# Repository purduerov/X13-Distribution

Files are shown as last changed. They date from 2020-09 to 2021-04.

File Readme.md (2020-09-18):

# Readme for X13-Distribution

Whenever you make a new part, download the datasheet and save it here _**and**_ with the part in the parts library

Always pull other people's changes before beginning to work
`git pull`

Be sure to push your changes after  working on them. Run:
1. `git add .` to add any files in this directory or a subdirectory
or `git add -u` to add any modified files
2. (Optional) `git clean -nX` to see what ignored files can be removed
	`git clean -fX` removes ignored files (Eagle backups)
3. `git commit -m "helpful commit message"` with a description of the work that you did
4. `git push` to push your work to github

Other helpful commands
* `git status` says information about modified and staged files
* `git log` shows the recent commits of the repository
* `git log filename.extension` show the recent commits for just that file
* `git checkout first-couple-letter-of-commit-id` lets you go back to a previous version
* `git checkout master` brings you back to the latest commit
* `git tag` lists the tags
* `git tag -a orderX -m "the version of the board placed for the X'th order"` tag a specific commit
* `git push --tags` needed to push tags to remote
* `git show orderX` show the commit log for the given tag
* `git checkout orderX` go back and interact with the files at the tagged commit

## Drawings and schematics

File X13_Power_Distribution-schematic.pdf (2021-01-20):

## 2 48V_POE

## 6 TETHER

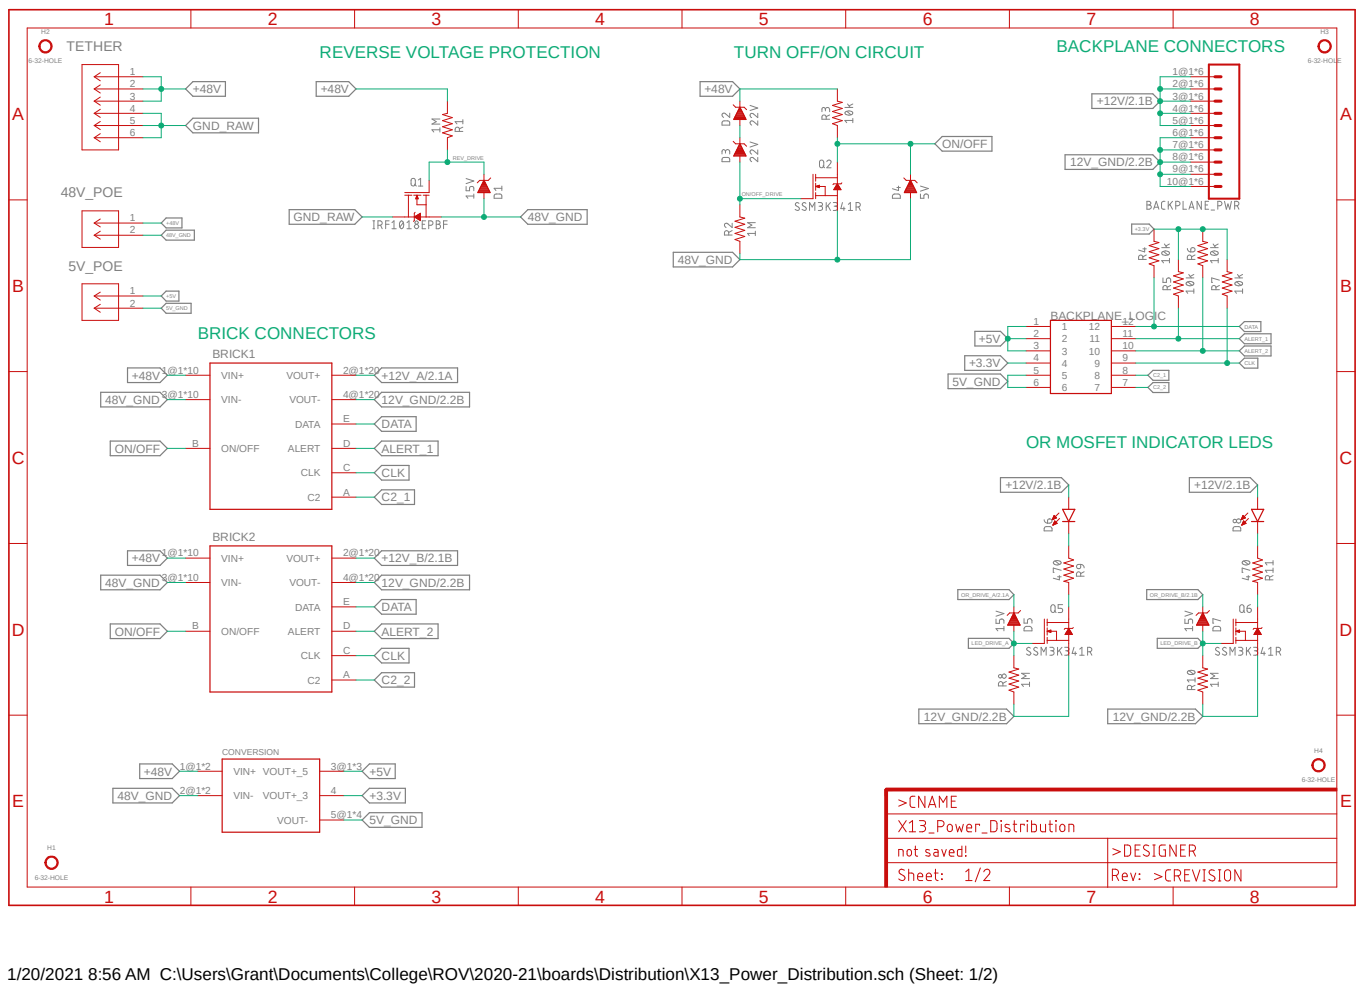
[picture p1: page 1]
2 5V_POE; 6-32-HOLE; VIN+ 1@1*2; VIN- 2@1*2; VOUT+_5; VOUT+_3; VOUT-; CONVERSION; 12 BACKPLANE_LOGIC; VIN+ 1@1*10; VIN- 3@1*10; VOUT+; ON/OFF B; DATA; ALERT; CLK; A BRICK1; A BRICK2; ON/OFF_DRIVE; ON/OFF; 48V_GND; CLK CLK; DATA DATA; 12V_GND/2.2B; GND_RAW; REV_DRIVE; OR_DRIVE_A/2.1A; OR_DRIVE_B/2.1B; ALERT_2; ALERT_1 ALERT_1; 5V_GND; LED_DRIVE_A; LED_DRIVE_B; REVERSE VOLTAGE PROTECTION; TURN OFF/ON CIRCUIT; BACKPLANE CONNECTORS; BRICK CONNECTORS

OR MOSFET INDICATOR LEDS

1/20/2021 8:56 AM C:\Users\Grant\Documents\College\ROV\2020-21\boards\Distribution\X13_Power_Distribution.sch (Sheet: 1/2)

LM5050

A

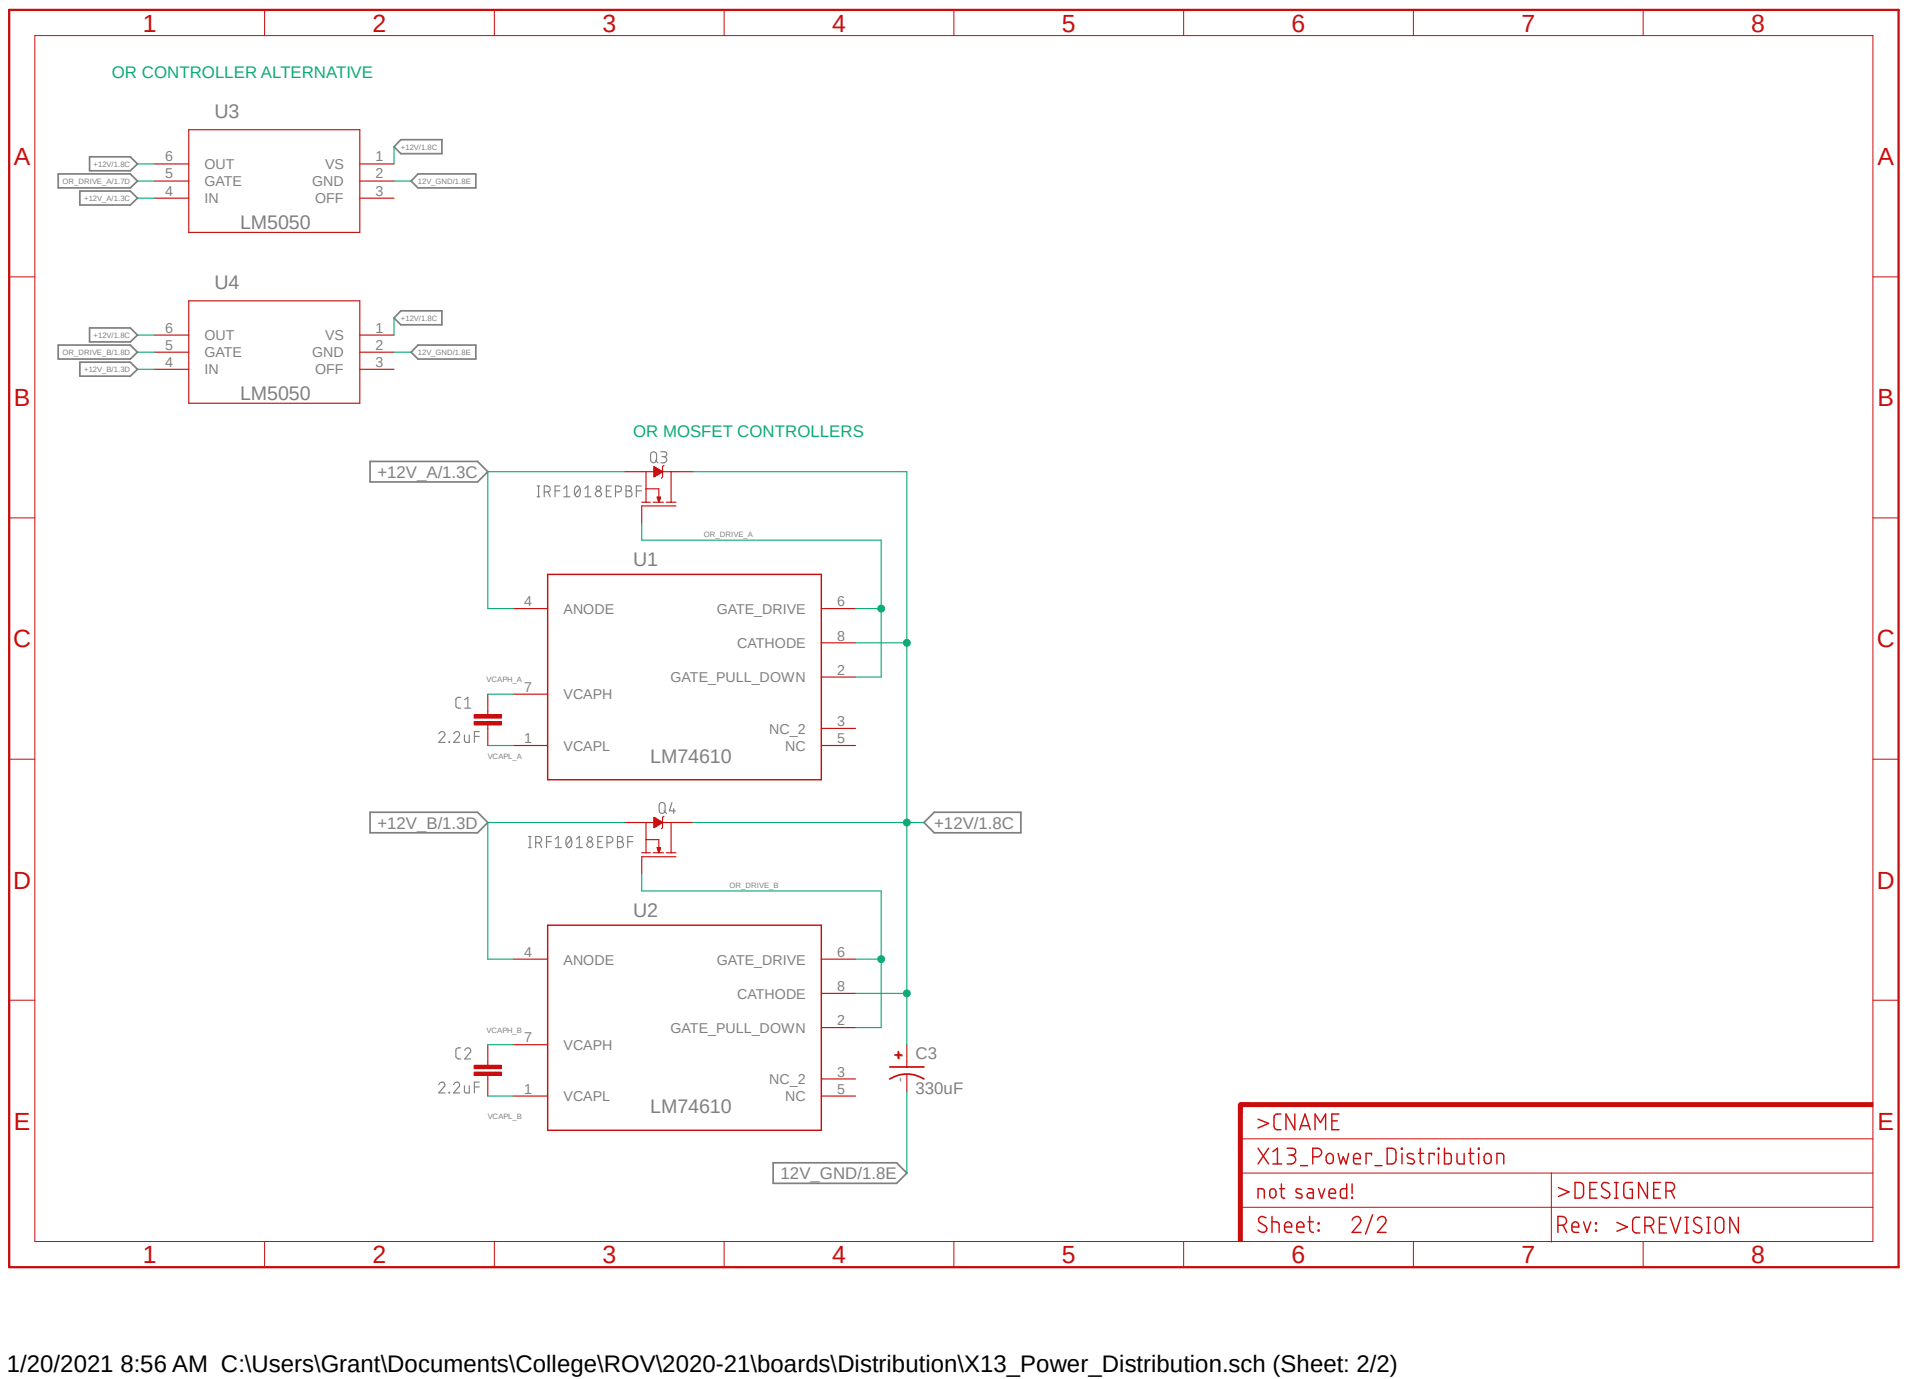
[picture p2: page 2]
VCAPL 1; GATE_PULL_DOWN; ANODE 4; GATE_DRIVE; VCAPH 7; CATHODE; GND; OFF; GATE 5; OUT 6; 12V_GND/1.8E; VCAPH_B; VCAPL_B; VCAPL_A; VCAPH_A; OR_DRIVE_A; OR_DRIVE_A/1.7D; OR_DRIVE_B; OR_DRIVE_B/1.8D A

OR CONTROLLER ALTERNATIVE

OR MOSFET CONTROLLERS

1/20/2021 8:56 AM C:\Users\Grant\Documents\College\ROV\2020-21\boards\Distribution\X13_Power_Distribution.sch (Sheet: 2/2)

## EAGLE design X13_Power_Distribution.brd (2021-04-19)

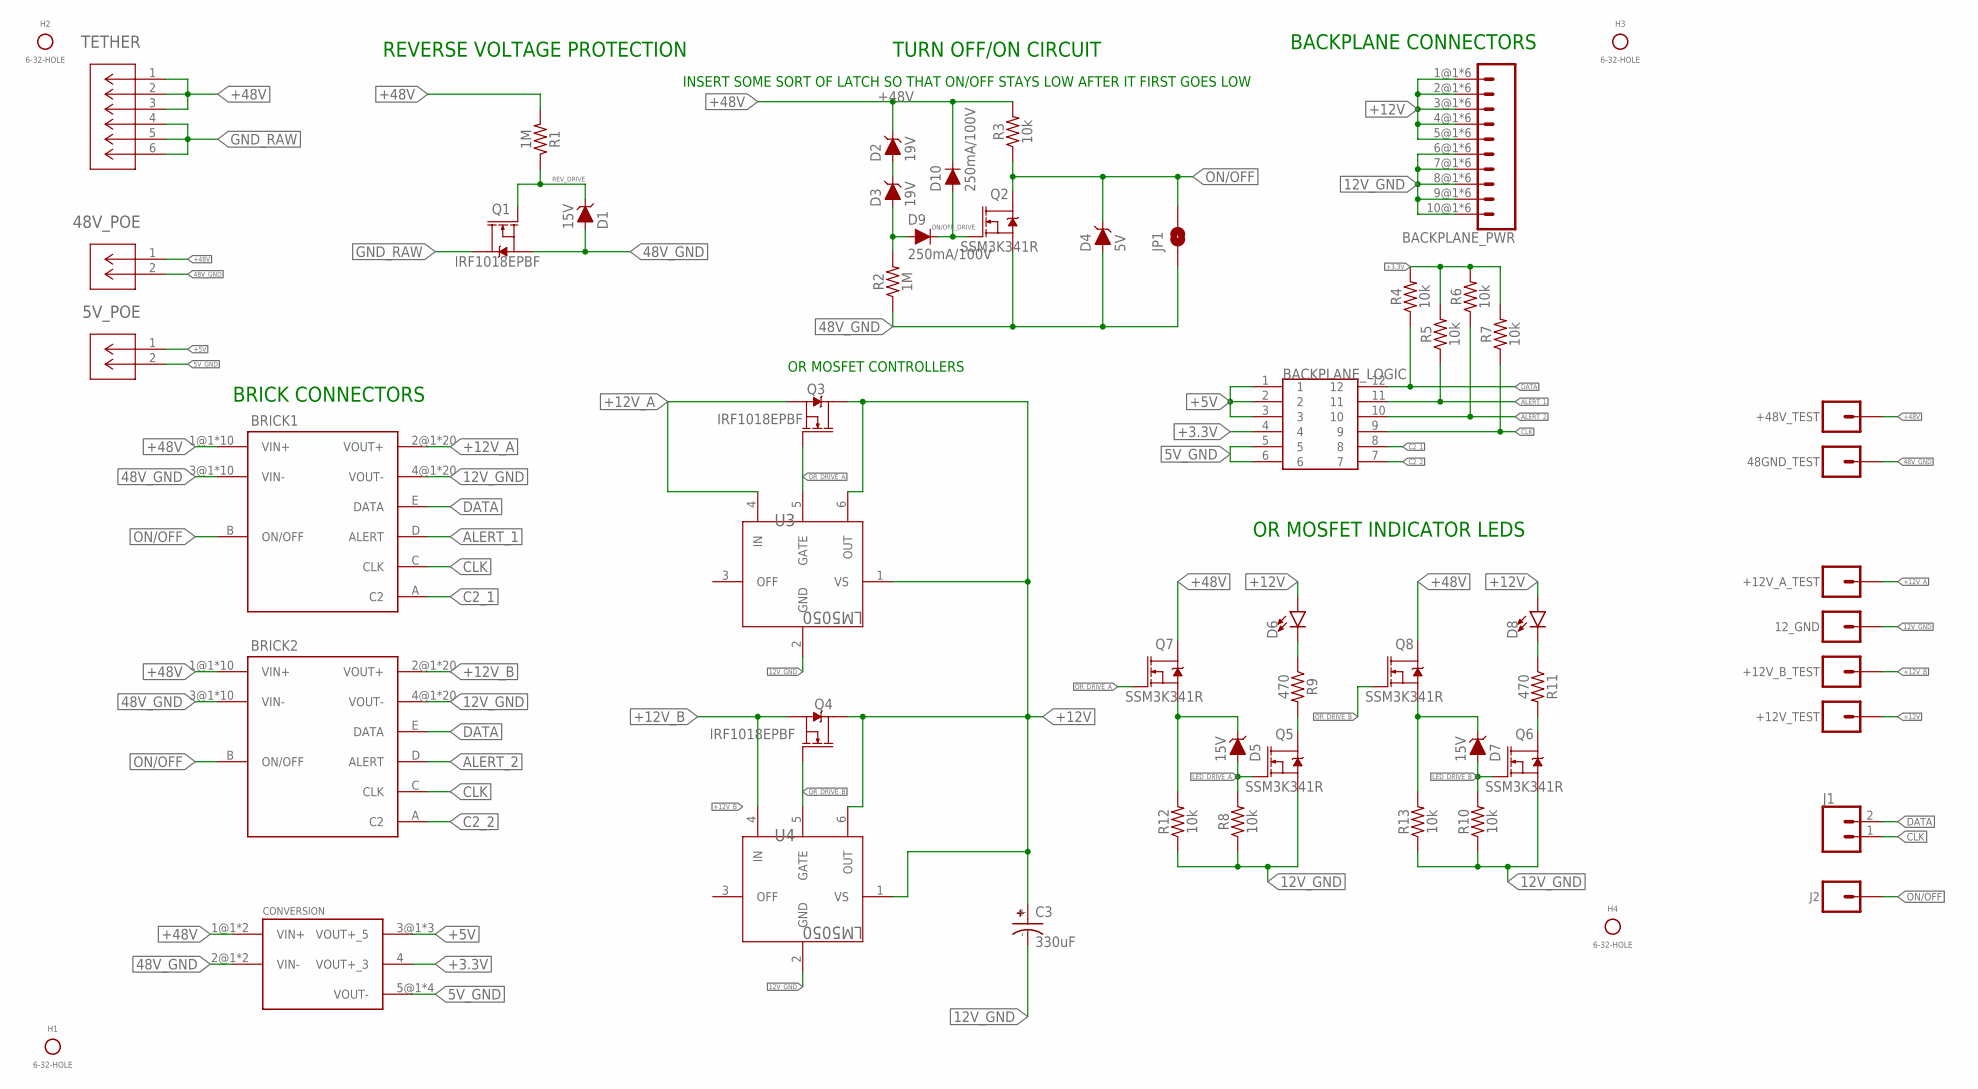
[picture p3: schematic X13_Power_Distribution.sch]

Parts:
5V_POE, 48V_POE: POE_TERMINAL; CONN2_282834-2_TEC
12_GND, 48GND_TEST: CONN_01; 1X01
+12V_A_TEST, +12V_B_TEST, +12V_TEST, +48V_TEST: CONN_01; 1X01
BACKPLANE_LOGIC: IPL1-106-01-L-D-K
BACKPLANE_PWR: MPPT-10-01-01-L-RA-SD
BRICK1, BRICK2: DIST2BRICKVER_D2; DIST2BRICK_D2
C3: 330uF; CAPAE1030X1050N
CONVERSION: DIST2CON
D1, D5, D7: 15V; SOD-323
D2, D3: 19V; SOD-323
D4: 5V; SOD-323
D6, D8: LED0603; LED-0603
D9, D10: 250mA/100V; SOD-323
H1, H2, H3, H4: 6-32-HOLE
J1: CONN_02; 1X02
J2: CONN_01; 1X01
JP1: JUMPER-SMT_2_NO_SILK; SMT-JUMPER_2_NO_SILK
Q1, Q3, Q4: IRF1018EPBF; TO263
Q2, Q5, Q6, Q7, Q8: SSM3K341R; SOT323
R1, R2: 1M; 0603
R3, R4, R5, R6, R7, R8, R10, R12, R13: 10k; 0603
R9, R11: 470; 0603
TETHER: 48V; CON6_P5MM_VER_TERM-BLK_TYC
U3, U4: LM5050; SOT-23-6

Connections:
5V_GND: 5V_POE.2, BACKPLANE_LOGIC.5, BACKPLANE_LOGIC.6, CONVERSION.5@1 (VOUT-), CONVERSION.5@2 (VOUT-), CONVERSION.5@3 (VOUT-), CONVERSION.5@4 (VOUT-)
12V_GND: 12_GND.1, BACKPLANE_PWR.6@1 (6), BACKPLANE_PWR.6@2 (6), BACKPLANE_PWR.6@3 (6), BACKPLANE_PWR.6@4 (6), BACKPLANE_PWR.6@5 (6), BACKPLANE_PWR.6@6 (6), BACKPLANE_PWR.7@1 (7), BACKPLANE_PWR.7@2 (7), BACKPLANE_PWR.7@3 (7), BACKPLANE_PWR.7@4 (7), BACKPLANE_PWR.7@5 (7), BACKPLANE_PWR.7@6 (7), BACKPLANE_PWR.8@1 (8), BACKPLANE_PWR.8@2 (8), BACKPLANE_PWR.8@3 (8), BACKPLANE_PWR.8@4 (8), BACKPLANE_PWR.8@5 (8), BACKPLANE_PWR.8@6 (8), BACKPLANE_PWR.9@1 (9), BACKPLANE_PWR.9@2 (9), BACKPLANE_PWR.9@3 (9), BACKPLANE_PWR.9@4 (9), BACKPLANE_PWR.9@5 (9), BACKPLANE_PWR.9@6 (9), BACKPLANE_PWR.10@1 (10), BACKPLANE_PWR.10@2 (10), BACKPLANE_PWR.10@3 (10), BACKPLANE_PWR.10@4 (10), BACKPLANE_PWR.10@5 (10), BACKPLANE_PWR.10@6 (10), BRICK1.4@1 (VOUT-), BRICK1.4@2 (VOUT-), BRICK1.4@3 (VOUT-), BRICK1.4@4 (VOUT-), BRICK1.4@5 (VOUT-), BRICK1.4@6 (VOUT-), BRICK1.4@7 (VOUT-), BRICK1.4@8 (VOUT-), BRICK1.4@9 (VOUT-), BRICK1.4@10 (VOUT-), BRICK1.4@11 (VOUT-), BRICK1.4@12 (VOUT-), BRICK1.4@13 (VOUT-), BRICK1.4@14 (VOUT-), BRICK1.4@15 (VOUT-), BRICK1.4@16 (VOUT-), BRICK1.4@17 (VOUT-), BRICK1.4@18 (VOUT-), BRICK1.4@19 (VOUT-), BRICK1.4@20 (VOUT-), BRICK2.4@1 (VOUT-), BRICK2.4@2 (VOUT-), BRICK2.4@3 (VOUT-), BRICK2.4@4 (VOUT-), BRICK2.4@5 (VOUT-), BRICK2.4@6 (VOUT-), BRICK2.4@7 (VOUT-), BRICK2.4@8 (VOUT-), BRICK2.4@9 (VOUT-), BRICK2.4@10 (VOUT-), BRICK2.4@11 (VOUT-), BRICK2.4@12 (VOUT-), BRICK2.4@13 (VOUT-), BRICK2.4@14 (VOUT-), BRICK2.4@15 (VOUT-), BRICK2.4@16 (VOUT-), BRICK2.4@17 (VOUT-), BRICK2.4@18 (VOUT-), BRICK2.4@19 (VOUT-), BRICK2.4@20 (VOUT-), C3.-, Q5.2 (S), Q6.2 (S), R8.1, R10.1, R12.1, R13.1, U3.2 (GND), U4.2 (GND)
48V_GND: 48GND_TEST.1, 48V_POE.2, BRICK1.3@1 (VIN-), BRICK1.3@2 (VIN-), BRICK1.3@3 (VIN-), BRICK1.3@4 (VIN-), BRICK1.3@5 (VIN-), BRICK1.3@6 (VIN-), BRICK1.3@7 (VIN-), BRICK1.3@8 (VIN-), BRICK1.3@9 (VIN-), BRICK1.3@10 (VIN-), BRICK2.3@1 (VIN-), BRICK2.3@2 (VIN-), BRICK2.3@3 (VIN-), BRICK2.3@4 (VIN-), BRICK2.3@5 (VIN-), BRICK2.3@6 (VIN-), BRICK2.3@7 (VIN-), BRICK2.3@8 (VIN-), BRICK2.3@9 (VIN-), BRICK2.3@10 (VIN-), CONVERSION.2@1 (VIN-), CONVERSION.2@2 (VIN-), D1.A, D4.A, JP1.1, Q1.2 (S), Q2.2 (S), R2.1
+3.3V: BACKPLANE_LOGIC.4, CONVERSION.4 (VOUT+_3), R4.2, R5.2, R6.2, R7.2
+5V: 5V_POE.1, BACKPLANE_LOGIC.1, BACKPLANE_LOGIC.2, BACKPLANE_LOGIC.3, CONVERSION.3@1 (VOUT+_5), CONVERSION.3@2 (VOUT+_5), CONVERSION.3@3 (VOUT+_5)
+12V: +12V_TEST.1, BACKPLANE_PWR.1@1 (1), BACKPLANE_PWR.1@2 (1), BACKPLANE_PWR.1@3 (1), BACKPLANE_PWR.1@4 (1), BACKPLANE_PWR.1@5 (1), BACKPLANE_PWR.1@6 (1), BACKPLANE_PWR.2@1 (2), BACKPLANE_PWR.2@2 (2), BACKPLANE_PWR.2@3 (2), BACKPLANE_PWR.2@4 (2), BACKPLANE_PWR.2@5 (2), BACKPLANE_PWR.2@6 (2), BACKPLANE_PWR.3@1 (3), BACKPLANE_PWR.3@2 (3), BACKPLANE_PWR.3@3 (3), BACKPLANE_PWR.3@4 (3), BACKPLANE_PWR.3@5 (3), BACKPLANE_PWR.3@6 (3), BACKPLANE_PWR.4@1 (4), BACKPLANE_PWR.4@2 (4), BACKPLANE_PWR.4@3 (4), BACKPLANE_PWR.4@4 (4), BACKPLANE_PWR.4@5 (4), BACKPLANE_PWR.4@6 (4), BACKPLANE_PWR.5@1 (5), BACKPLANE_PWR.5@2 (5), BACKPLANE_PWR.5@3 (5), BACKPLANE_PWR.5@4 (5), BACKPLANE_PWR.5@5 (5), BACKPLANE_PWR.5@6 (5), C3.+, D6.A, D8.A, Q3.3 (D), Q4.3 (D), U3.1 (VS), U3.6 (OUT), U4.1 (VS), U4.6 (OUT)
+12V_A: +12V_A_TEST.1, BRICK1.2@1 (VOUT+), BRICK1.2@2 (VOUT+), BRICK1.2@3 (VOUT+), BRICK1.2@4 (VOUT+), BRICK1.2@5 (VOUT+), BRICK1.2@6 (VOUT+), BRICK1.2@7 (VOUT+), BRICK1.2@8 (VOUT+), BRICK1.2@9 (VOUT+), BRICK1.2@10 (VOUT+), BRICK1.2@11 (VOUT+), BRICK1.2@12 (VOUT+), BRICK1.2@13 (VOUT+), BRICK1.2@14 (VOUT+), BRICK1.2@15 (VOUT+), BRICK1.2@16 (VOUT+), BRICK1.2@17 (VOUT+), BRICK1.2@18 (VOUT+), BRICK1.2@19 (VOUT+), BRICK1.2@20 (VOUT+), Q3.2 (S), U3.4 (IN)
+12V_B: +12V_B_TEST.1, BRICK2.2@1 (VOUT+), BRICK2.2@2 (VOUT+), BRICK2.2@3 (VOUT+), BRICK2.2@4 (VOUT+), BRICK2.2@5 (VOUT+), BRICK2.2@6 (VOUT+), BRICK2.2@7 (VOUT+), BRICK2.2@8 (VOUT+), BRICK2.2@9 (VOUT+), BRICK2.2@10 (VOUT+), BRICK2.2@11 (VOUT+), BRICK2.2@12 (VOUT+), BRICK2.2@13 (VOUT+), BRICK2.2@14 (VOUT+), BRICK2.2@15 (VOUT+), BRICK2.2@16 (VOUT+), BRICK2.2@17 (VOUT+), BRICK2.2@18 (VOUT+), BRICK2.2@19 (VOUT+), BRICK2.2@20 (VOUT+), Q4.2 (S), U4.4 (IN)
+48V: 48V_POE.1, +48V_TEST.1, BRICK1.1@1 (VIN+), BRICK1.1@2 (VIN+), BRICK1.1@3 (VIN+), BRICK1.1@4 (VIN+), BRICK1.1@5 (VIN+), BRICK1.1@6 (VIN+), BRICK1.1@7 (VIN+), BRICK1.1@8 (VIN+), BRICK1.1@9 (VIN+), BRICK1.1@10 (VIN+), BRICK2.1@1 (VIN+), BRICK2.1@2 (VIN+), BRICK2.1@3 (VIN+), BRICK2.1@4 (VIN+), BRICK2.1@5 (VIN+), BRICK2.1@6 (VIN+), BRICK2.1@7 (VIN+), BRICK2.1@8 (VIN+), BRICK2.1@9 (VIN+), BRICK2.1@10 (VIN+), CONVERSION.1@1 (VIN+), CONVERSION.1@2 (VIN+), D2.C, D10.C, Q7.3 (D), Q8.3 (D), R1.2, R3.2, TETHER.1, TETHER.2, TETHER.3
ALERT_1: BACKPLANE_LOGIC.11, BRICK1.D (ALERT), R5.1
ALERT_2: BACKPLANE_LOGIC.10, BRICK2.D (ALERT), R6.1
C2_1: BACKPLANE_LOGIC.8, BRICK1.A (C2)
C2_2: BACKPLANE_LOGIC.7, BRICK2.A (C2)
CLK: BACKPLANE_LOGIC.9, BRICK1.C (CLK), BRICK2.C (CLK), J1.1, R7.1
DATA: BACKPLANE_LOGIC.12, BRICK1.E (DATA), BRICK2.E (DATA), J1.2, R4.1
GND_RAW: Q1.3 (D), TETHER.4, TETHER.5, TETHER.6
LED_DRIVE_A: D5.A, Q5.1 (G), R8.2
LED_DRIVE_B: D7.A, Q6.1 (G), R10.2
unnamed: D2.A, D3.C
unnamed: D5.C, Q7.2 (S), R12.2
unnamed: D7.C, Q8.2 (S), R13.2
unnamed: Q5.3 (D), R9.2
unnamed: D6.C, R9.1
unnamed: Q6.3 (D), R11.2
unnamed: D8.C, R11.1
ON/OFF: BRICK1.B (ON/OFF), BRICK2.B (ON/OFF), D4.C, J2.1, JP1.2, Q2.3 (D), R3.1
ON/OFF_DRIVE: D9.C, D10.A, Q2.1 (G)
ON_DETECT: D3.A, D9.A, R2.2
OR_DRIVE_A: Q3.1 (G), Q7.1 (G), U3.5 (GATE)
OR_DRIVE_B: Q4.1 (G), Q8.1 (G), U4.5 (GATE)
REV_DRIVE: D1.C, Q1.1 (G), R1.1

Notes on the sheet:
TURN OFF/ON CIRCUIT
REVERSE VOLTAGE PROTECTION
OR MOSFET CONTROLLERS
OR MOSFET INDICATOR LEDS
BACKPLANE CONNECTORS
BRICK CONNECTORS
INSERT SOME SORT OF LATCH SO THAT ON/OFF STAYS LOW AFTER IT FIRST GOES LOW

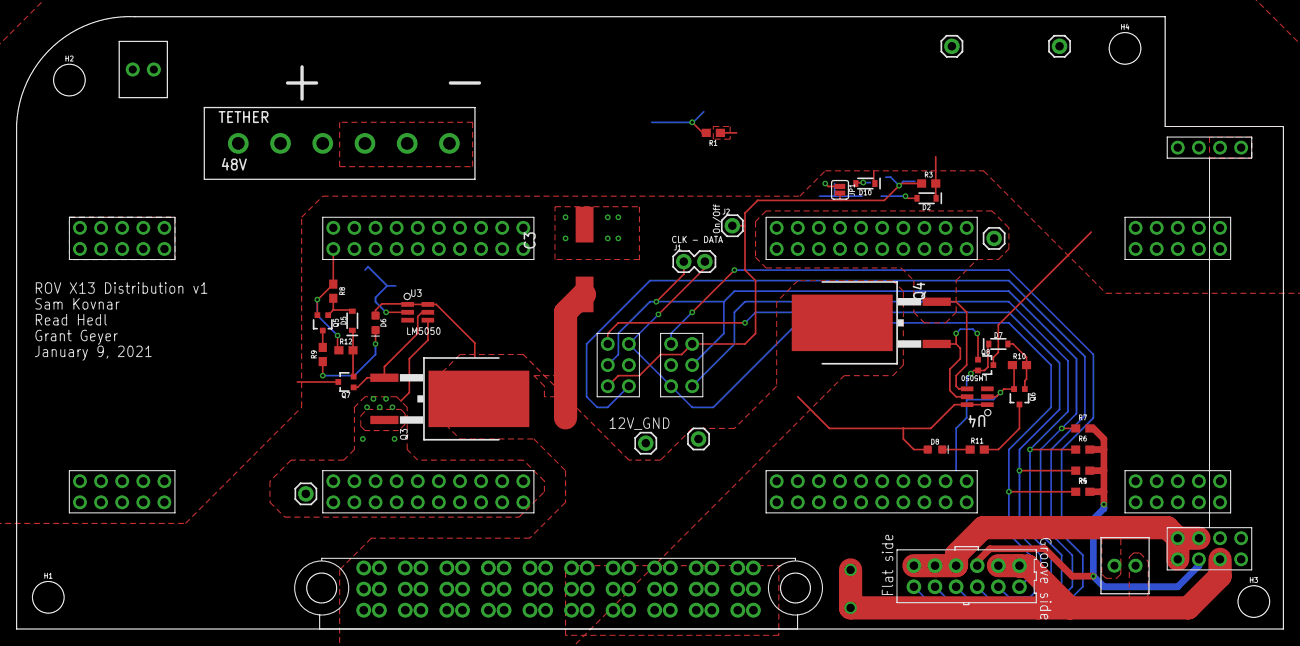
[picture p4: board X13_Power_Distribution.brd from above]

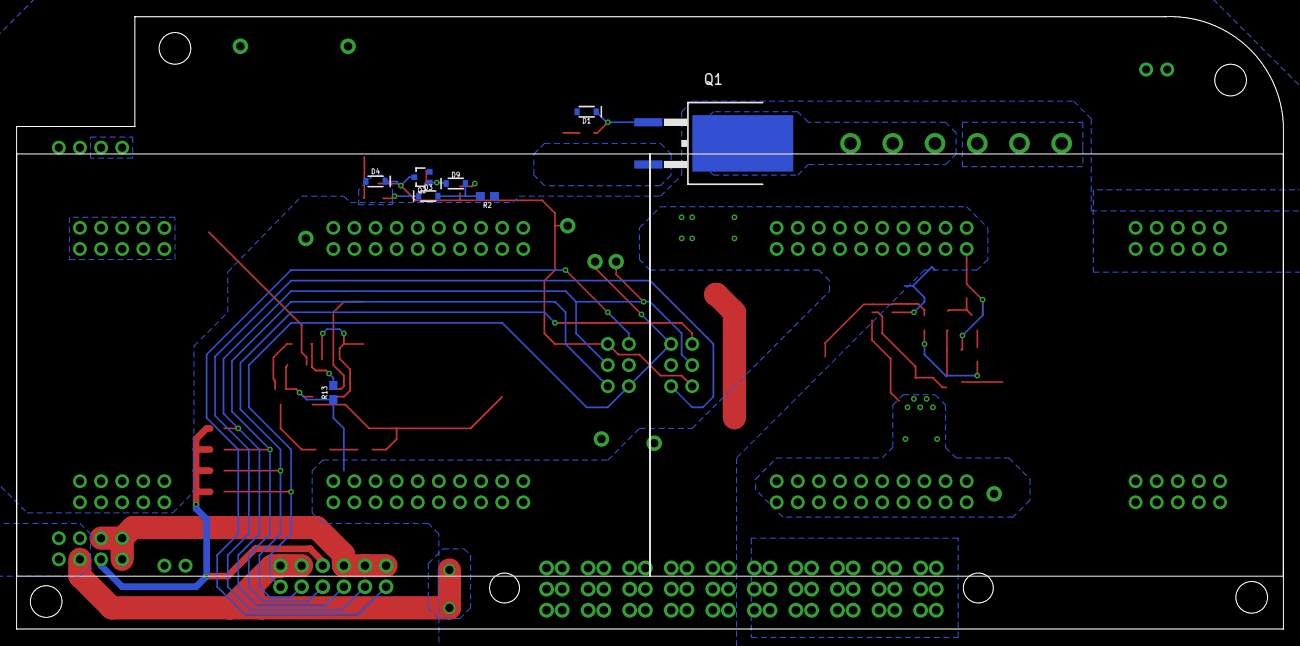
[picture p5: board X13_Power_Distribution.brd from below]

Board: 2 copper layers, 152.4 x 73.7 mm, 55 parts (8 on the bottom side), 31 nets.

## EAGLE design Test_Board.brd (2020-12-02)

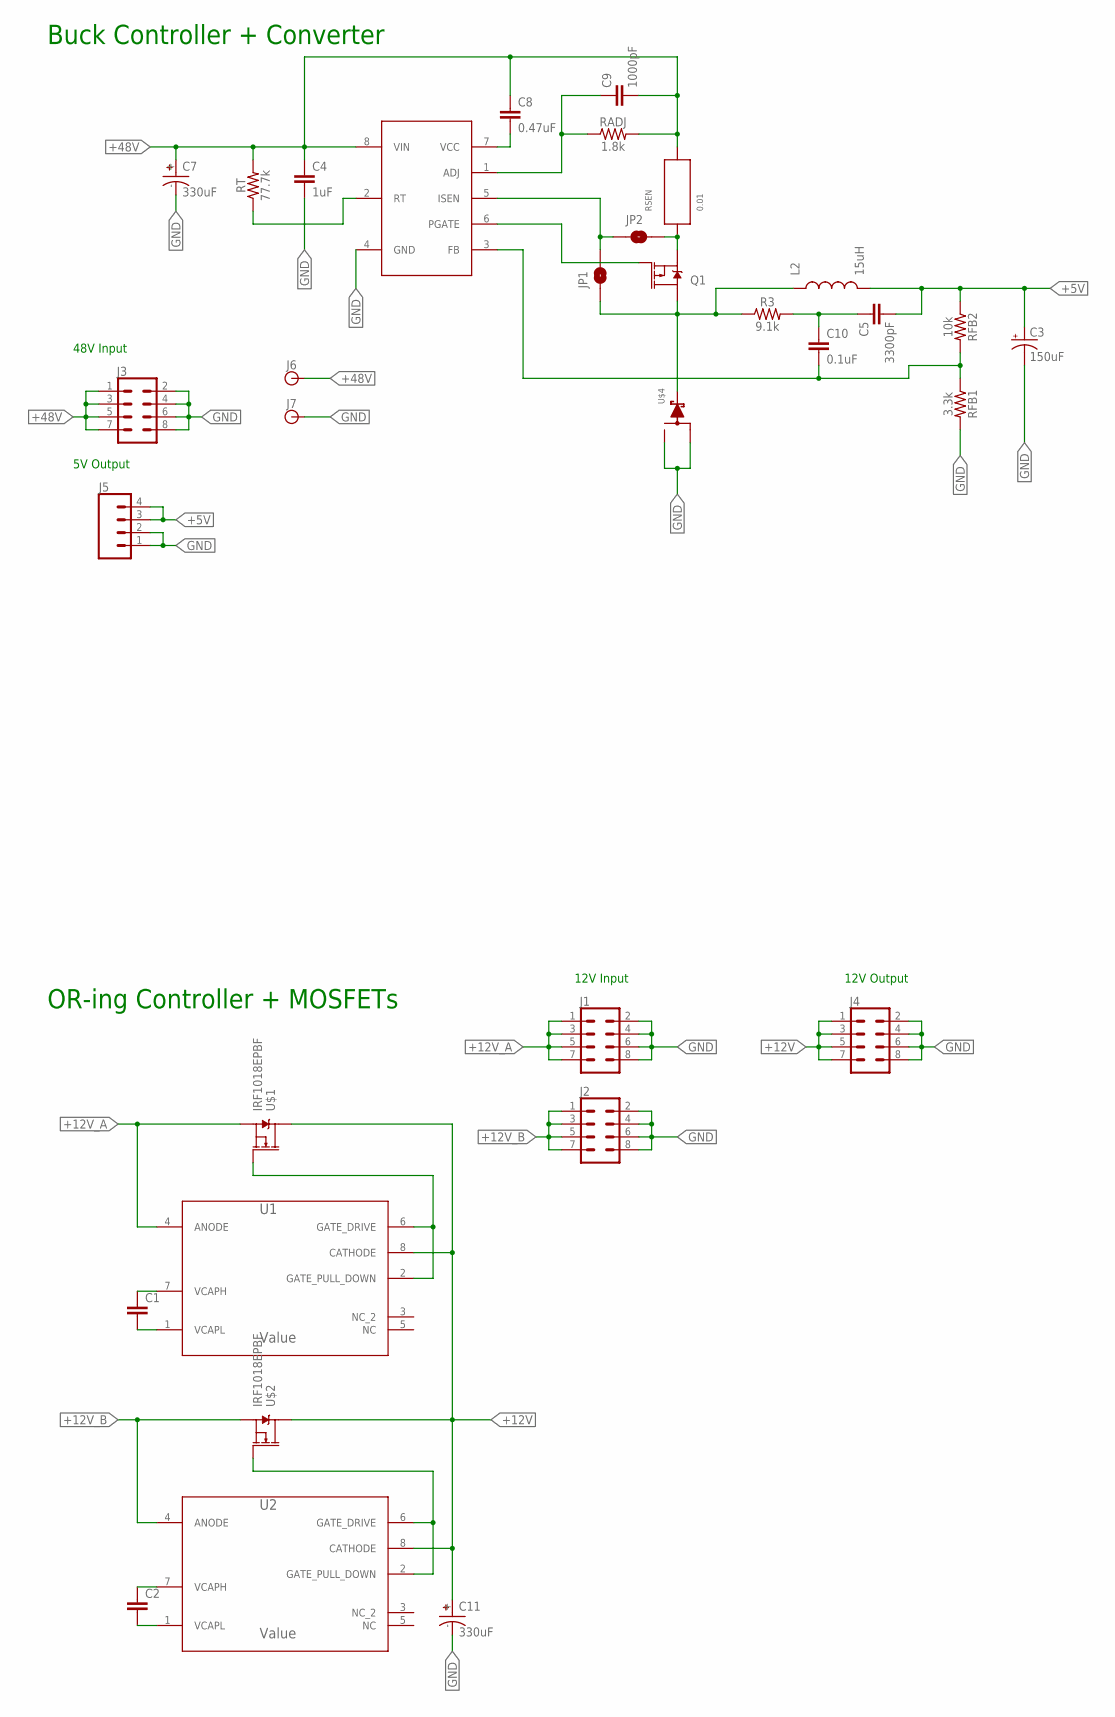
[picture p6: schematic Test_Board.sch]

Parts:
C1, C2: 0.1UF-0603-100V-10%; 0603
C3: 150uF; CTAN(7.30_4.30MM)
C4: 1uF; 0603
C5: 3300pF; 0603
C7, C11: 330uF; CAPAE1030X1050N
C8: 0.47uF; 0603
C9: 1000pF; 0603
C10: 0.1uF; 0603
J1, J2, J3, J4: CONN_04X2; 2X4
J5: CONN_041X04_NO_SILK; 1X04_NO_SILK
J6, J7: BANANA_CONN
JP1, JP2: JUMPER-SMT_2_NO_NO-SILK; SMT-JUMPER_2_NO_NO-SILK
L2: 15uH; HCMA1305
Q1: MOSFET_PCH-NDS8434; SO08
R3: 9.1k; 0603
RADJ: 1.8k; 0603
RFB1: 3.3k; 0603
RFB2: 10k; 0603
RSEN: 0.01; CSS2H-2512
RT: 77.7k; 0603
U1, U2: Value; DGK0008A_M
U$1, U$2: IRF1018EPBF; TO263
U$3: LM5085
U$4: SWITCHMODE_SCHOTTKY; DPAK-3

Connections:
+5V: C3.+, C5.2, J5.3, J5.4, L2.2, RFB2.1
+12V: C11.+, J4.1, J4.3, J4.5, J4.7, U1.8 (CATHODE), U2.8 (CATHODE), U$1.3 (D), U$2.3 (D)
+12V_A: J1.1, J1.3, J1.5, J1.7, U1.4 (ANODE), U$1.2 (S)
+12V_B: J2.1, J2.3, J2.5, J2.7, U2.4 (ANODE), U$2.2 (S)
+48V: C4.1, C7.+, C8.1, C9.2, J3.1, J3.3, J3.5, J3.7, J6.P$1, RADJ.2, RSEN.2, RT.2, U$3.8 (VIN)
FB: C10.2, RFB1.1, RFB2.2, U$3.3 (FB)
GATE: Q1.4 (G), U$3.6 (PGATE)
GND: C3.-, C4.2, C7.-, C11.-, J1.2, J1.4, J1.6, J1.8, J2.2, J2.4, J2.6, J2.8, J3.2, J3.4, J3.6, J3.8, J4.2, J4.4, J4.6, J4.8, J5.1, J5.2, J7.P$1, RFB1.2, U$3.4 (GND), U$4.P$1, U$4.P$3
ISEN: JP1.2, JP2.1, U$3.5 (ISEN)
unnamed: C9.1, RADJ.1, U$3.1 (ADJ)
unnamed: C2.1, U2.7 (VCAPH)
unnamed: C2.2, U2.1 (VCAPL)
unnamed: C1.2, U1.1 (VCAPL)
unnamed: C1.1, U1.7 (VCAPH)
unnamed: U1.2 (GATE_PULL_DOWN), U1.6 (GATE_DRIVE), U$1.1 (G)
unnamed: C5.1, C10.1, R3.2
unnamed: U2.2 (GATE_PULL_DOWN), U2.6 (GATE_DRIVE), U$2.1 (G)
unnamed: JP2.2, Q1.1 (S), Q1.2 (S), Q1.3 (S), RSEN.1
RT: RT.1, U$3.2 (RT)
SW: JP1.1, L2.1, Q1.5 (D), Q1.6 (D), Q1.7 (D), Q1.8 (D), R3.1, U$4.P$4
VCC: C8.2, U$3.7 (VCC)

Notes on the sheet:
OR-ing Controller + MOSFETs
Buck Controller + Converter
48V Input
5V Output
12V Input
12V Output

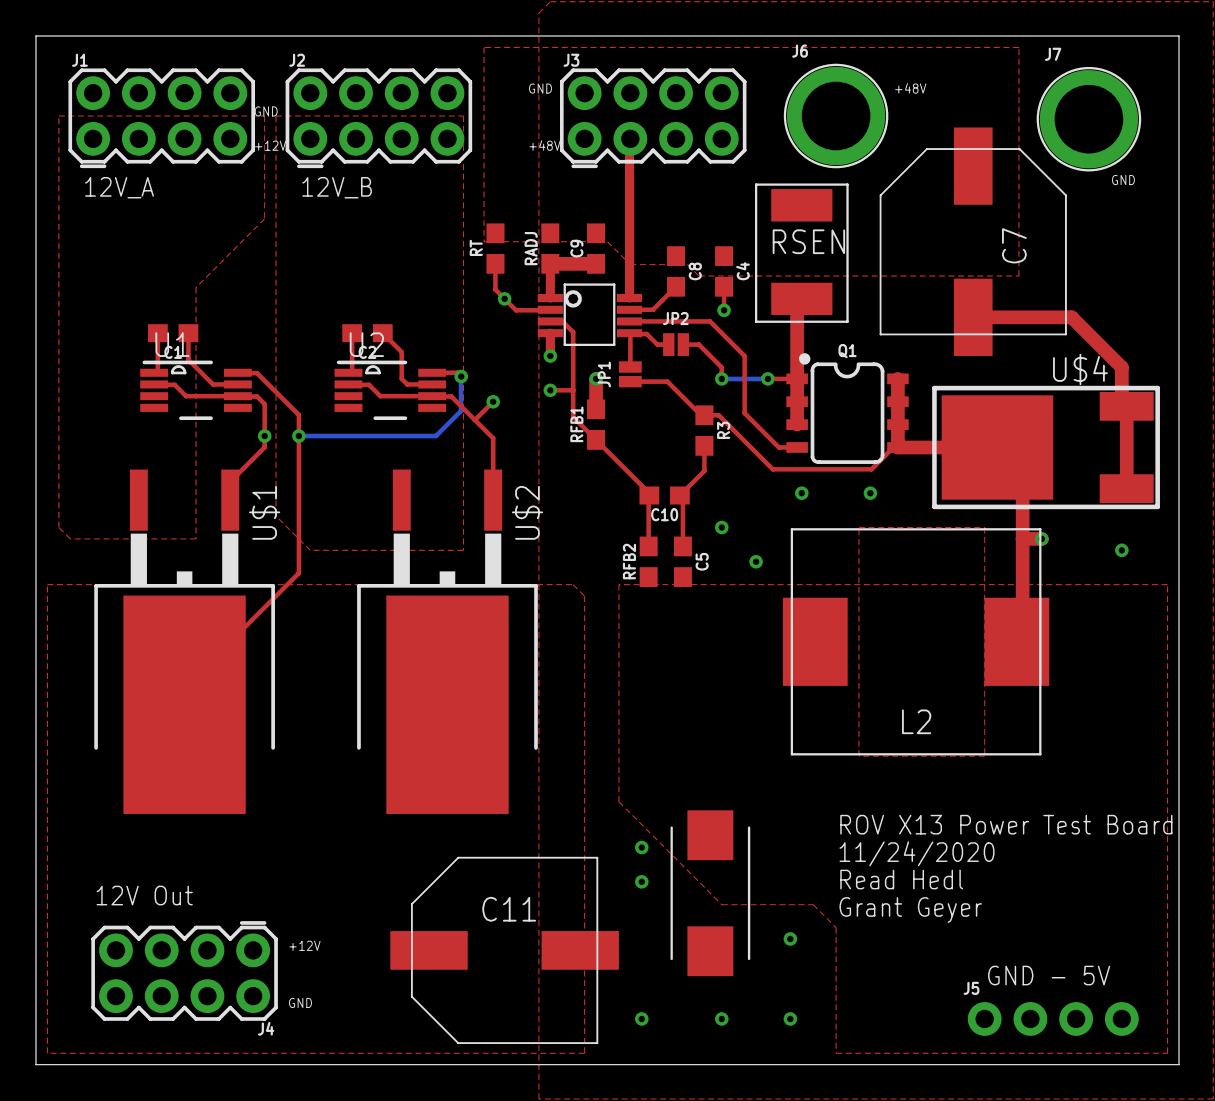
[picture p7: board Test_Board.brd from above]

Board: 2 copper layers, 63.5 x 57.1 mm, 33 parts (0 on the bottom side), 21 nets.

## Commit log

2020-10-07 made da schematic
    [X13_Power_Distribution.sch]
2020-10-10 Made some slight changes
    [X13_Power_Distribution.sch]
2020-10-14 goodbye microcontroller
    [X13_Power_Distribution.sch]
2020-10-17 Added the diodes :))
    [X13_Power_Distribution.sch]
2020-10-17 Starting on connectors
    [X13_Power_Distribution.sch]
2020-10-21 Added placeholders
    [X13_Power_Distribution.sch]
2020-10-21 removed the custom conversion connector
    [X13_Power_Distribution.sch]
2020-10-23 ready for design review 1 :3
    [X13_Power_Distribution.sch]
2020-10-25 center frame in schematic and add board dimension
    [X13_Power_Distribution.brd, X13_Power_Distribution.sch]
2020-10-29 am sleepy
    [X13_Power_Distribution.brd, X13_Power_Distribution.sch]
2020-10-31 It's pretty now :3
    [X13_Power_Distribution.brd, X13_Power_Distribution.sch]
2020-10-31 moved the bus connectors a bit
    [X13_Power_Distribution.sch]
2020-11-14 Design review time
    [X13_Power_Distribution.brd, X13_Power_Distribution.sch]
2020-11-14 cap placeholders fixed
    [X13_Power_Distribution.brd, X13_Power_Distribution.sch]
2020-11-19 started test board, adjusting Buck controller
    [Test_Board.brd, Test_Board.sch]
2020-11-21 initial placements done
    [Test_Board.brd, Test_Board.sch]
2020-11-22 finished routing, but dont have senior design DRC on my PC to check
    [Test_Board.brd, Test_Board.sch]
2020-11-22 finished routing. Need DRC
    [Test_Board.brd, Test_Board.sch]
2020-11-22 added sense resistor
    [Test_Board.brd, Test_Board.sch]
2020-11-22 rerouted buck converter, trying to mitigate distance and also follow the recommended layout
    [Test_Board.brd, Test_Board.sch]
2020-11-24 adjusted buck controller
    [Test_Board.brd]
2020-11-24 Added U-shape for external wire
    [Test_Board.brd]
2020-11-24 bigger U and a few labels. inductor pour cutout
    [Test_Board.brd, Test_Board.sch]
2020-11-24 couple silkscreen changes to order
    [Test_Board.brd, Test_Board.sch]
2020-12-02 routed :)
    [X13_Power_Distribution.brd, X13_Power_Distribution.sch]
2020-12-04 Routed with custom connectors
    [X13_Power_Distribution.brd, X13_Power_Distribution.sch]
2020-12-05 Fixed some DRC errors
    [X13_Power_Distribution.brd, X13_Power_Distribution.sch]
2020-12-05 B is a second version that uses the Version B connectors
    [X13_Power_Distribution_B.brd, X13_Power_Distribution_B.sch]
2020-12-21 Version C! Uses connector C!
    [X13_Power_Distribution_C.brd, X13_Power_Distribution_C.sch]
2020-12-22 5V and 3.3V traces are wider now
    [X13_Power_Distribution_C.brd]
2020-12-23 Moved ON/OFF, moved a diode
    [X13_Power_Distribution_C.brd, X13_Power_Distribution_C.sch]
2020-12-23 Two LEDs where once was one
    [X13_Power_Distribution_C.brd, X13_Power_Distribution_C.sch]
2020-12-23 Some tweaks and labeling
    [X13_Power_Distribution_C.brd, X13_Power_Distribution_C.sch]
2020-12-26 Moved 5V Ethernet, added some cutouts
    [X13_Power_Distribution_C.brd]
2021-01-03 Jan 2nd Tweaks
    [X13_Power_Distribution_C.brd]
2021-01-03 Moved capacitor over a bit more
    [X13_Power_Distribution_C.brd]
2021-01-04 Added LM5050, tweaks
    [X13_Power_Distribution_C.brd, X13_Power_Distribution_C.sch]
2021-01-04 More tweaks
    [X13_Power_Distribution_C.brd, X13_Power_Distribution_C.sch]
2021-01-06 Version D :/
    [X13_Power_Distribution_D.brd, X13_Power_Distribution_D.sch]
2021-01-06 Version D2 -_-
    [X13_Power_Distribution_D1.brd, X13_Power_Distribution_D1.sch]
2021-01-06 Uses brick connector vD2
    [X13_Power_Distribution_D.brd, X13_Power_Distribution_D1.brd, X13_Power_Distribution_D1.sch]
2021-01-06 Brick Connector D2
    [X13_Power_Distribution_D1.brd]
2021-01-11 Exports and cleaning up git for ordering
    [X13_Power_Distribution.brd, X13_Power_Distribution.sch, X13_Power_Distribution.step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]
2021-01-11 playing with 3d package generator in eagle
    [X13_Power_Distribution.brd, X13_Power_Distribution.sch, X13_Power_Distribution.step]
2021-01-20 Fix misprint in schematic
2021-03-15 Made some slight changes to thermals
    [X13_Power_Distribution.brd]
2021-03-18 Some more edits
    [X13_Power_Distribution.brd, X13_Power_Distribution.sch]
2021-03-20 Made some more lil tweaks
    [X13_Power_Distribution.brd, X13_Power_Distribution.step]
2021-04-05 Lower on/off threshold, remove old unused or-ing controller, try new 12V on LED circuit
    [X13_Power_Distribution.brd, X13_Power_Distribution.sch]
2021-04-17 Add solder jumper to short on/off and diode to latch voltage
    [X13_Power_Distribution.brd, X13_Power_Distribution.sch]
2021-04-19 Add diode to on/off to discharge gate when power supply hits 0
    [X13_Power_Distribution.brd, X13_Power_Distribution.sch]

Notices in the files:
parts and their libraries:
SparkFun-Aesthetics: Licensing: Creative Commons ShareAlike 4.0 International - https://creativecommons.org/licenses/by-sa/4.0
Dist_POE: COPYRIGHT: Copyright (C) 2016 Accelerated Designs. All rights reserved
